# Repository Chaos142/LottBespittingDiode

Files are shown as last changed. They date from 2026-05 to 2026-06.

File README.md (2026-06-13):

# Lott-Bespitting Diode (LBD)

A high-intensity IR blaster built on the RP2040. Browser-native control over WebSerial, MOSFET-driven IR output, 38kHz NEC modulation. Fully open source.

[Home Page](https://chaowoses.github.io/LottBespittingDiode/) &middot; [Controller](https://chaowoses.github.io/LottBespittingDiode/controller.html)

Named for Mrs. Lott, the worst teacher I ever had, and her classroom projector.

---

## Features

- **Web Controller**: Full single-page app to manage IR remotes, browse the Flipper-IRDB, compose NEC signals, and transmit over WebSerial
- **In-Browser Schematic Viewer**: Browse all hardware schematics directly on the landing page via KiCanvas
- **Auto-Generated BOM**: Bill of materials extracted from KiCad schematics and embedded in the landing page, updated on every push
- **IRDB Integration**: Browse and import from [Lucaslhm/Flipper-IRDB](https://github.com/Lucaslhm/Flipper-IRDB) directly from the controller
- **NEC Protocol Engine**: CircuitPython firmware with hardware-timed 38kHz carrier modulation
- **Library Management**: Organize remotes and signals in folders with drag-and-drop, favorites, and inline editing

---

## Project Structure

```
app/                  # Web front-end
  index.html          # Landing page (hero, BOM, schematic viewer, docs)
  index.css           # Landing page styles (dark theme, purple/amber)
  index.js            # Landing page interactivity (tabs, viewer)
  controller.html     # WebSerial controller app
  style.css           # Controller styles
  script.js           # Controller logic (serial, library, IRDB, transmit)
  three-scene.js      # Three.js particle background

firmware/             # CircuitPython firmware
  code.py             # NEC protocol engine over USB serial
  lib/                # Runtime libraries

hardware/             # KiCad hardware design
  LBD.kicad_sch       # Main schematic (RP2040, MOSFET, IR matrix)
  power.kicad_sch     # Power regulation (TPSM828214SILR)
  flash.kicad_sch     # External flash (W25Q128)
  usb.kicad_sch       # USB-C (USB4155)
  prototype/prototype.kicad_sch # Breadboard/perfboard prototype variant
  LBD.kicad_pcb       # PCB layout

scripts/              # Utility scripts
  generate_bom.py     # Auto-generates BOM HTML from KiCad schematics
  ir_tester.py        # Standalone IR transmission test
```

---

## Hardware

> The embedded PCB design isn't finalized yet. Build the prototype on a breadboard or perfboard using the [prototype schematic](hardware/prototype.kicad_sch).

The full design targets a custom PCB with an RP2040, MOSFET-switched IR LED array, USB-C, and external flash. Five KiCad schematics cover the main board, power regulation, flash memory, USB connector, and a simplified prototype variant.

---

## Firmware

The [CircuitPython firmware](firmware/code.py) implements a standard NEC protocol engine:

- 38kHz carrier modulation via `pulseio.PulseOut`
- Listens for 4-byte NEC arrays over USB serial
- Drives a status LED and the IR output on GPIO
- Header: 9000&micro;s mark / 4500&micro;s space
- Bit coding: 560&micro;s mark + 1690&micro;s (1) or 560&micro;s (0)
- Compatible with any NEC IR receiver

```python
import time
import board
import pwmio

# 38kHz carrier wave initialization
ir_pwm = pwmio.PWMOut(board.GP16, frequency=38000, duty_cycle=0)

def pulse_nec(mark_us, space_us):
    # Enable carrier wave modulation for duration of mark
    ir_pwm.duty_cycle = 32768  # 50% duty cycle
    time.sleep_us(mark_us)

    # Disable carrier wave modulation for duration of space
    ir_pwm.duty_cycle = 0
    time.sleep_us(space_us)
```

---

## Web Interface

Two pages are served via GitHub Pages:

| Page | Description |
|---|---|
| **Landing Page** (`index.html`) | Project overview, BOM table, KiCanvas schematic viewer, architecture docs, features, setup guide |
| **Controller** (`controller.html`) | Full WebSerial-based remote control app with library management, IRDB browser, signal composer, and transmit history |

---

## Setup & Flash

> Build the prototype on a breadboard or perfboard using the [prototype schematic](hardware/prototype.kicad_sch).

<details>
<summary><strong>DIY / Prototype Only</strong>: Steps 1 and 2 (skip if you have a pre-assembled unit)</summary>

### Step 1: Enter Bootloader Mode

Press and hold the **BOOT** button on the board, then connect it to your computer via a data-capable USB cable. Release the button once the drive mounts.

### Step 2: Install CircuitPython

A mass storage volume named `RPI-RP2` will appear. Drag and drop the appropriate CircuitPython `.uf2` payload onto its root directory. The board will automatically reboot and remount as `CIRCUITPY`.

</details>

### Step 3: Deploy Firmware

Copy the contents of `firmware/` onto the `CIRCUITPY` volume root:

- `code.py`
- `lib/`

### Step 4: Plug It In & Open the Controller

Keep the device connected via USB, then open the [web controller](https://chaowoses.github.io/LottBespittingDiode/controller.html) in a Chromium-based browser. Click **Connect** to establish the WebSerial session.

To run locally (required for development):

```bash
git clone https://github.com/chaowoses/LottBespittingDiode.git
cd LottBespittingDiode
python -m http.server 8080
# open http://localhost:8080
```

---

## License & Terms of Use

> [!CAUTION]
> **STRICTLY PROHIBITED FOR ILLEGAL USE**
>
> This project is designed solely for personal engineering research, hardware prototyping, and authorized testing.
> You may only operate this device on equipment you personally own or have explicit permission to control.
> The creator assumes no liability for misuse, property disruption, or equipment damage.

This project (software, firmware, schematics, PCB layouts, and documentation) is licensed under the **GNU General Public License v3.0 (GPL-3.0)**.

Copyright &copy; 2026 Josh Felder (Chaos). All Rights Reserved.

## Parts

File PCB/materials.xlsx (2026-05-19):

Description | Manufacturer | Manufacturer Part Number | Digikey Part Number | Link | Quantity | Libraries | Datasheet
ARM® Cortex®-M0+ - Microcontroller IC 32-Bit Dual-Core 133MHz External Program Memory 56-QFN (7x7) | Raspberry Pi | SC0914(13) | 2648-SC0914(13)CT-ND | https://www.digikey.com/en/products/detail/raspberry-pi/SC0914-13/14306015 | 1 | https://www.digikey.com/en/models/14306010 | https://datasheets.raspberrypi.com/rp2040/rp2040-datasheet.pdf
USB-C (USB TYPE-C) USB 3.2 Gen 2 (USB 3.1 Gen 2, Superspeed + (USB 3.1)) Plug Connector 24 Position Board Edge, Surface Mount; Through Hole, Right Angle | GCT | USB4155-03-C | 2073-USB4155-03-CCT-ND | https://www.digikey.com/en/products/detail/gct/USB4155-03-C/14305161 | 1 | https://www.digikey.com/en/models/14305161?tab=snapmagic | https://gct.co/files/specs/usb4155-spec.pdf
Infrared (IR) Emitter 940nm 1.46V 100mA 92mW/sr @ 100mA (Typ) 30° 1210 (3225 Metric) | Inolux | IN-S126ESGHIR | 1830-IN-S126ESGHIRCT-ND | https://www.digikey.com/en/products/detail/inolux/IN-S126ESGHIR/10384762 | 12 | https://www.digikey.com/en/models/10384762?tab=ultralibrarian | http://www.inolux-corp.com/datasheet/IR/Emitter/940%20nm%20SMD/IN-S126ESGHIR_V1.0.pdf
N-Channel 30 V 5.7A (Ta) 1.4W (Ta) Surface Mount SOT-23-3 | Alpha & Omega Semiconductor Inc. | AO3400A | 785-1000-1-ND | https://www.digikey.com/en/products/detail/alpha-omega-semiconductor-inc/AO3400A/1855772 | 1 | https://www.digikey.com/en/models/1855772?tab=snapmagic | https://mm.digikey.com/Volume0/opasdata/d220001/medias/docus/1133/AO3400A_ds.pdf
6.2 Ohms ±1% 0.25W, 1/4W Chip Resistor 1206 (3216 Metric) Automotive AEC-Q200 Thick Film | Stackpole Electronics Inc | RMCF1206FT6R20 | RMCF1206FT6R20CT-ND | https://www.digikey.com/en/products/detail/stackpole-electronics-inc/RMCF1206FT6R20/2417449 | 3 | https://www.digikey.com/en/models/2417449?tab=ultralibrarian | https://www.seielect.com/catalog/SEI-RMCF_RMCP.pdf
10 kOhms ±1% 0.125W, 1/8W Chip Resistor 0805 (2012 Metric) Automotive AEC-Q200 Thick Film | Stackpole Electronics Inc | RMCF0805FT10K0 | RMCF0805FT10K0CT-ND | https://www.digikey.com/en/products/detail/stackpole-electronics-inc/RMCF0805FT10K0/1760676 | 1 | https://www.digikey.com/en/models/1760676?tab=ultralibrarian | https://www.seielect.com/catalog/SEI-RMCF_RMCP.pdf
27.4 Ohms ±1% 0.25W, 1/4W Chip Resistor 1206 (3216 Metric) Automotive AEC-Q200 Thick Film | Stackpole Electronics Inc | RMCF1206FT27R4 | RMCF1206FT27R4CT-ND | https://www.digikey.com/en/products/detail/stackpole-electronics-inc/RMCF1206FT27R4/1759794 | 2 | https://www.digikey.com/en/models/1759794?tab=ultralibrarian | https://www.seielect.com/catalog/SEI-RMCF_RMCP.pdf
Switching Voltage Regulators 5.5-V input 1-A ste p-down module with i |  |  |  | https://www.mouser.com/ProductDetail/Texas-Instruments/TPSM828214SILR?qs=iLbezkQI%252BsibRGaNc1MtTA%3D%3D |  |  | https://www.digikey.com/en/models/14124001?tab=ultralibrarian
22 µF ±20% 10V Ceramic Capacitor X5R 0603 (1608 Metric) |  |  |  | https://www.digikey.com/en/products/detail/samsung-electro-mechanics/CL10A226MP8NUNE/3886932
4.7 µF ±10% 10V Ceramic Capacitor X7R 0603 (1608 Metric) |  |  |  | https://www.digikey.com/en/products/detail/cal-chip-electronics-inc/GMC10X7R475K10NT/24343641
FLASH - NOR Memory IC 128Mbit SPI - Quad I/O, QPI 133 MHz 8-SOIC |  | W25Q128JVSIQ |  | https://www.digikey.com/en/products/detail/winbond-electronics/W25Q128JVSIQ/5803943
Tactile Switch SPST-NO Top Actuated Surface Mount |  | PTS636SM43SMTR LFS |  | https://www.digikey.com/en/products/detail/c-k/PTS636SM43SMTR-LFS/10071723 |  | Button_Switch_SMD:SW_Push_6x3.5mm
Crystals Ultra Miniature Ceramic SMD Crystal |  | STDCRG1-12M |  | https://www.mouser.com/ProductDetail/ABRACON/ABM8-272-T3?qs=QpmGXVUTftEj6miOiJBMxQ%3D%3D

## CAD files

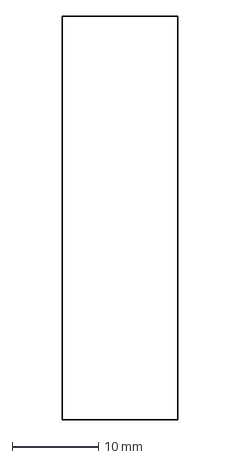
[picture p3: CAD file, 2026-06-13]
ref/usb/ProposedPCBOutline.dxf
13.4 x 46.9 mm

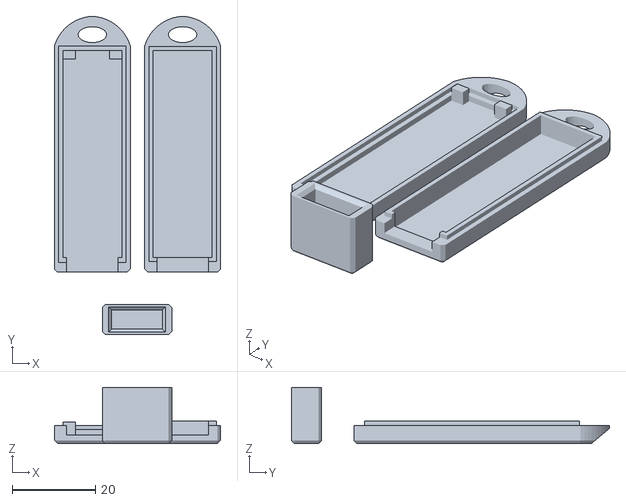
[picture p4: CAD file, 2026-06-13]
ref/usb/Corsair_Voyager_GT.stl
39.9 x 76.5 x 13.5

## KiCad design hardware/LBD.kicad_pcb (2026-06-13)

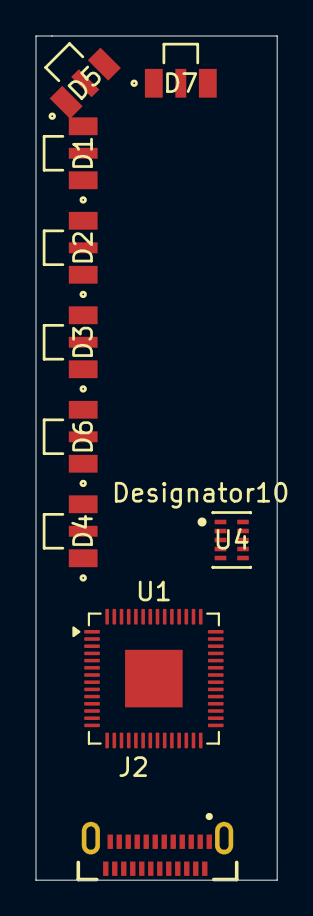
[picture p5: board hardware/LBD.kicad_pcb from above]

Board: 2 copper layers, 13.4 x 46.9 mm, 10 parts (0 on the bottom side), 7 nets, no tracks yet.

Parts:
D1, D2, D3, D4, D5, D6, D7: LED; LED_IN-S12_INL
J2: USB4155-03-C_REVA; GCT_USB4155-03-C_REVA
U1: RP2040; QFN-56-1EP_7x7mm_P0.4mm_EP3.2x3.2mm
U4: TPSM828214SILR

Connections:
+1V1: U1.23 (DVDD), U1.45 (VREG_VOUT), U1.50 (DVDD)
+3.3V: U1.1 (IOVDD), U1.10 (IOVDD), U1.22 (IOVDD), U1.33 (IOVDD), U1.42 (IOVDD), U1.43 (ADC_AVDD), U1.44 (VREG_VIN), U1.48 (USB_VDD), U1.49 (IOVDD), U4.5 (VOUT), U4.6 (VOUT), U4.7 (VOUT), U4.8 (FB)
/Power/PG: U1.26 (RUN), U4.4 (PG)
/USB/DN: J2.A7 (DN1), J2.B7 (DN2)
/USB/DP: J2.A6 (DP1), J2.B6 (DP2)
GND: J2.A1 (GND_A), J2.A12 (GND_A__1), J2.B1 (GND_B), J2.B12 (GND_B__1), J2.S1 (SHELL_GND), J2.S2 (SHELL_GND__1), U1.19 (TESTEN), U1.57 (GND), U4.9 (GND), U4.10 (GND)
VBUS: J2.A4 (VBUS_A), J2.A9 (VBUS_A__1), J2.B4 (VBUS_B), J2.B9 (VBUS_B__1), U4.1 (VIN), U4.2 (VIN), U4.3 (EN)

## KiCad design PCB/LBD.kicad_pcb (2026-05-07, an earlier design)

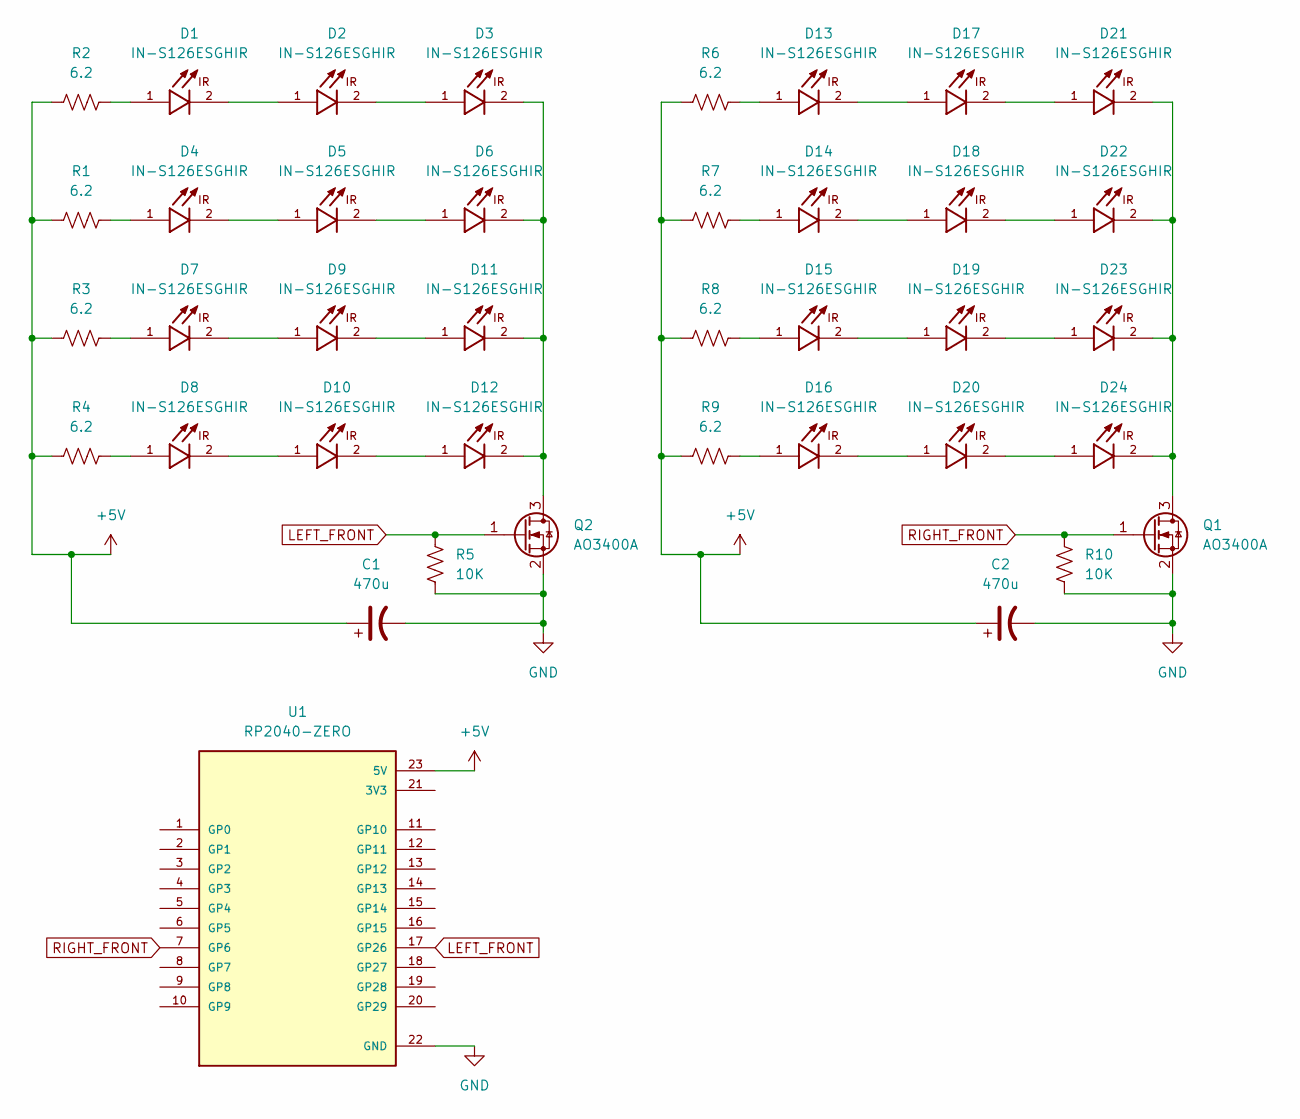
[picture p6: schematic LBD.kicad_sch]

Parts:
C1, C2: 470u; CP_Elec_8x10.5
D1, D2, D3, D4, D5, D6, D7, D8, D9, D10, D11, D12, D13, D14, D15, D16, D17, D18, D19, D20, D21, D22, D23, D24: IN-S126ESGHIR; LED_IN-S126ESGHIR; PARTREV 03-17-2020
Q1, Q2: AO3400A; SOT-23
R1, R2, R3, R4, R6, R7, R8, R9: 6.2; R_1206_3216Metric
R5, R10: 10K; R_0805_2012Metric
U1: RP2040-ZERO; MODULE_RP2040-ONE; PARTREV NA

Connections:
+5V: C1.1, C2.1, R1.1, R2.1, R3.1, R4.1, R6.1, R7.1, R8.1, R9.1, U1.23 (5V)
GND: C1.2, C2.2, Q1.2 (S), Q2.2 (S), R5.2, R10.2, U1.22 (GND)
LEFT_FRONT: Q2.1 (G), R5.1, U1.17 (GP26)
unnamed: D1.1, R2.2
unnamed: D1.2, D2.1
unnamed: D2.2, D3.1
unnamed: D4.1, R1.2
unnamed: D4.2, D5.1
unnamed: D5.2, D6.1
unnamed: D7.1, R3.2
unnamed: D7.2, D9.1
unnamed: D8.1, R4.2
unnamed: D8.2, D10.1
unnamed: D10.2, D12.1
unnamed: D9.2, D11.1
unnamed: D13.1, R6.2
unnamed: D13.2, D17.1
unnamed: D14.1, R7.2
unnamed: D14.2, D18.1
unnamed: D15.1, R8.2
unnamed: D15.2, D19.1
unnamed: D16.1, R9.2
unnamed: D16.2, D20.1
unnamed: D17.2, D21.1
unnamed: D18.2, D22.1
unnamed: D19.2, D23.1
unnamed: D20.2, D24.1
unnamed: D21.2, D22.2, D23.2, D24.2, Q1.3 (D)
unnamed: D3.2, D6.2, D11.2, D12.2, Q2.3 (D)
RIGHT_FRONT: Q1.1 (G), R10.1, U1.7 (GP6)

Board: 2 copper layers, 39 parts (0 on the bottom side), 30 nets, no tracks yet.

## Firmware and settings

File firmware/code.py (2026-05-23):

import sys
import time
import board
import pulseio
import digitalio
import adafruit_irremote

status_led = digitalio.DigitalInOut(board.GP16)
status_led.direction = digitalio.Direction.OUTPUT

pulseout = pulseio.PulseOut(board.GP0, frequency=38000, duty_cycle=2**15)

encoder = adafruit_irremote.GenericTransmit(
    header=[9000, 4500],
    one=[560, 1690],
    zero=[560, 560],
    trail=560
)

try:
    import select
except ImportError:
    import pulseio as select

print("[SYS] Core firmware engine online.\r")
print("[SYS] Awaiting pre-compiled 4-byte arrays from web controller...\r")

input_buffer = ""

while True:
    if sys.stdin in select.select([sys.stdin], [], [], 0)[0]:
        char = sys.stdin.read(1)
        
        if char == "\n" or char == "\r":
            clean_package = input_buffer.strip()
            
            if clean_package:
                try:
                    nec_payload = [int(x) for x in clean_package.split(",")]
                    
                    if len(nec_payload) != 4:
                        print(f"[ERR] Packet rejected! Expected 4 bytes, received {len(nec_payload)}\r")
                    else:
                        status_led.value = True
                        print(f"[HW] Processing transmission stream array -> {nec_payload}\r")
                        
                        encoder.transmit(pulseout, nec_payload)
                            
                        print("[OK] Signal cleared output hardware timers.\r")
                        
                except ValueError:
                    print("[ERR] Packet corrupted! Array items must be purely comma-separated integers.\r")
                except Exception as error:
                    print(f"[ERR] Hardware collision: {error}\r")
                
                status_led.value = False
                
            input_buffer = ""
        else:
            input_buffer += char
            
    time.sleep(0.001)

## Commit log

2026-05-07 started bom
    [LBD.kicad_pcb, LBD.kicad_sch, bom.xlsx]
2026-05-17 worked on schematic
    [LBD.kicad_sch, bom.xlsx, materials.xlsx]
2026-05-19 finished core, flash, crystal oscillator, and power regulation
    [Adafruit Feather RP2040 USB Host.kicad_sch, Adafruit Feather RP2040 USB Host.sch, Adafruit_Feather_RP2040_USB_Host_2.kicad_sch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]
2026-06-01 cleaned up schematic
    [Adafruit Feather RP2040 USB Host.kicad_sch, Adafruit_Feather_RP2040_USB_Host_2.kicad_sch, LBD.kicad_sch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]
2026-06-06 fixed schematic render path
2026-06-06 reorganized buttons
2026-06-06 fixed schematic rendering ... again
2026-06-06 added prototype schematic
    [prototype.kicad_sch]
2026-06-13 started placing leds
    [Corsair_Voyager_GT.stl, LBD.kicad_pcb, LBD.kicad_sch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]
2026-06-13 Update BOM from schematics [skip ci]

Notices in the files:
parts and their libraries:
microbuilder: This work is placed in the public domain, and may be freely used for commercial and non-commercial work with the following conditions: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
